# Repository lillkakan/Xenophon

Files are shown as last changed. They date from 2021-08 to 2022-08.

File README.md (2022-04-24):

# Xenophon split keyboard

Xenophon is a split keyboard with a design based on the ErgoDox EZ but for less keys for the thumps and another layout for the side keys.

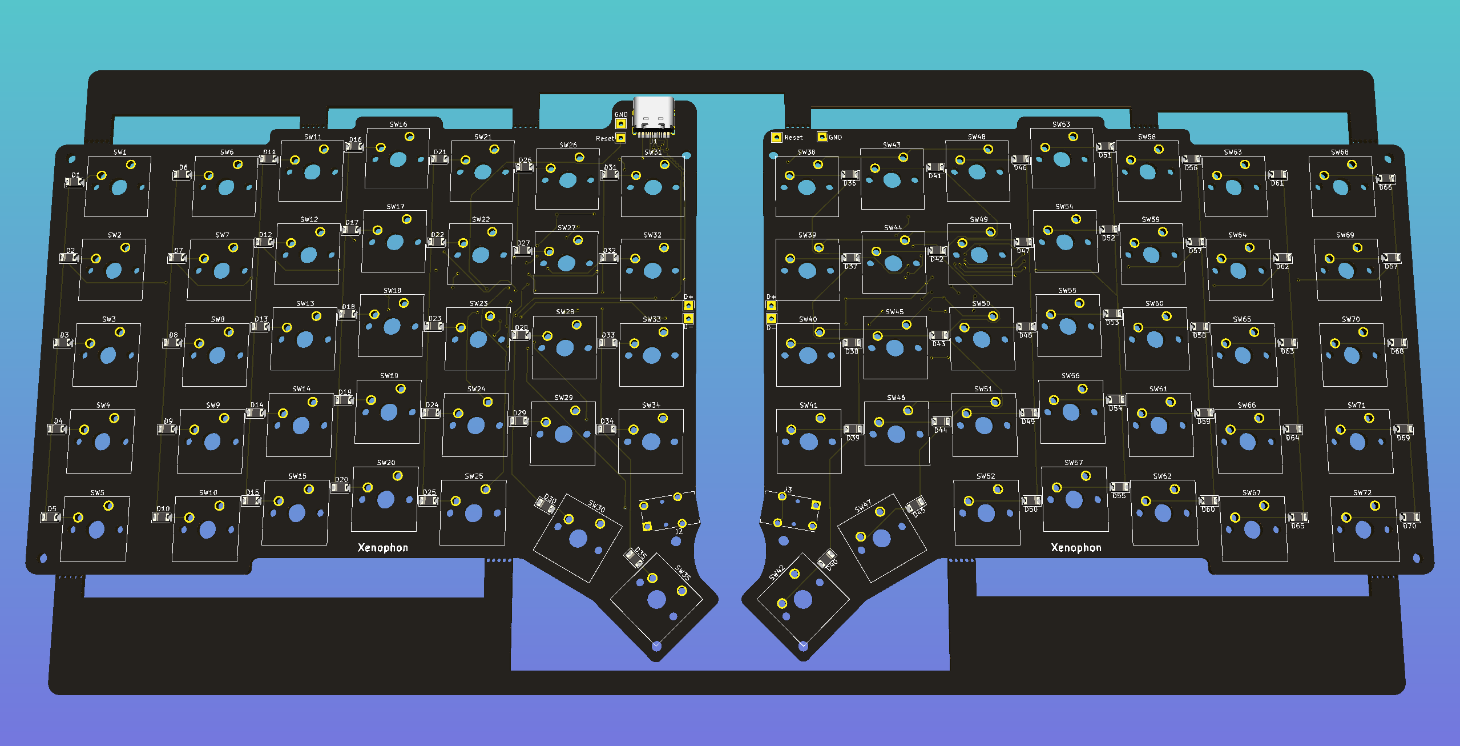
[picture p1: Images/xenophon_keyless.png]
The PCB for the keyboard.


## Features

### Ortholinear design

The keyboard features an ortholinear design based on the ErgoDox EZ.

### 70 buttons

The keyboard features 70 buttons to replicate a standard 60% keyboard as much as possible.
The Default layout is in swedish and has all the letters and numbers.

### TRS jack connection

The PCB is designed with a trs jack nicley placed between the tilted keys.
The two processors sent data through the serial bitbang protocol.

### Smart flashing design

I did not want to include a usb port on the right PCB i added two usb pins (D+ and D-) on both sides so that i could solder all the componens except the left processors and flash the right side easily.

### USB-C

The PCB features a usb type c port with capability to connect via a usb-c to usb-c cable or a standard usb-c to usb-a cable.

### 3D printable chassi

The chassi for the keyboard is 3D printable and is designed to be as small as possible while still protecting the PCB and the electrical components.

### Relativly low cost

The total cost of the key board is around 1 300 SEK.
Which is less than similar keyboards like the ErgoDox EZ.

## Made with

Quantum Mechanical Keyboard Firmware: [qmk_firmware](https://github.com/qmk/qmk_firmware)

### Made with help from

Keyboard layout editor: [keyboard-layout-editor.com](http://www.keyboard-layout-editor.com/)

Parametric Mechanical Keycap Library: [KeyV2](https://github.com/rsheldiii/KeyV2)

Keyboard Firmware Builder: [kbfirmware.com](https://kbfirmware.com/)

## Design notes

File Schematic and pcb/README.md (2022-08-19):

# Xenophon Schematic and PCB

### Schematic

Feutures a usb-c connection on the left (master) side.

Because I wanted the right PCB to have as few IO connectors as possible i made the decision to place two pin holes connected to the USB pins on the processor.
This made is so I could connect the USB pins on the left side with the ones on the right side and flash the right processor with the USB-C cable before i soldered the left processor.
The two pins can also be connected to two resistors and soldered to a USB cable to flash to the processor directly.

Small reset buttons take up unneccesary space on the pcb i added pins for for both sides reset connection designed so that a regular cable could pull the reset down.

### Components

- 70x Cherry switches
- 70x Diodes
- 1x  USB-C Receptacle
- 2x  Atmega 32u4
- 2x  16 Mhz Crystal
- 2x  3.5 TRS jack
- 5x  0.1u  Capacitor
- 4x  18p   Capacitor
- 2x  1u    Capacitor
- 1x  4.7u  Capacitor
- 4x  10k   Ohm Resistors
- 2x  22    Ohm Resistors
- 2x  5.1k  Ohm Resistors

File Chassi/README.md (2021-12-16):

# Xenophon

The base is made using FreeCAD and can be 3D printed and applied to the PCB directly.

The PCB features small stud holes which fits on the studs on the chassi.
Because these holes are small there is a stud tester i printed to confirm that my 3D printers settings would work.

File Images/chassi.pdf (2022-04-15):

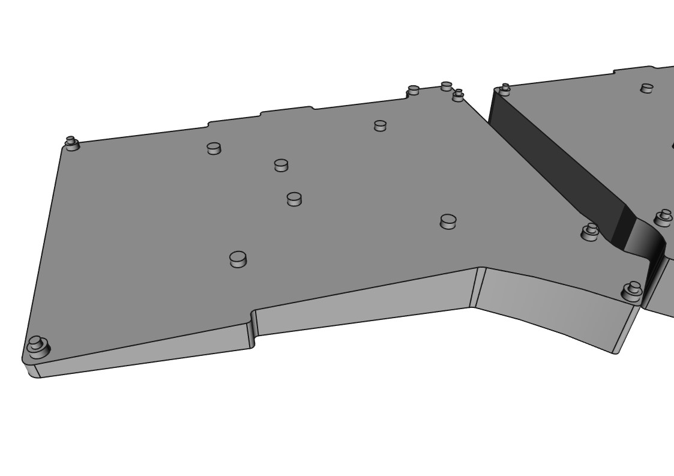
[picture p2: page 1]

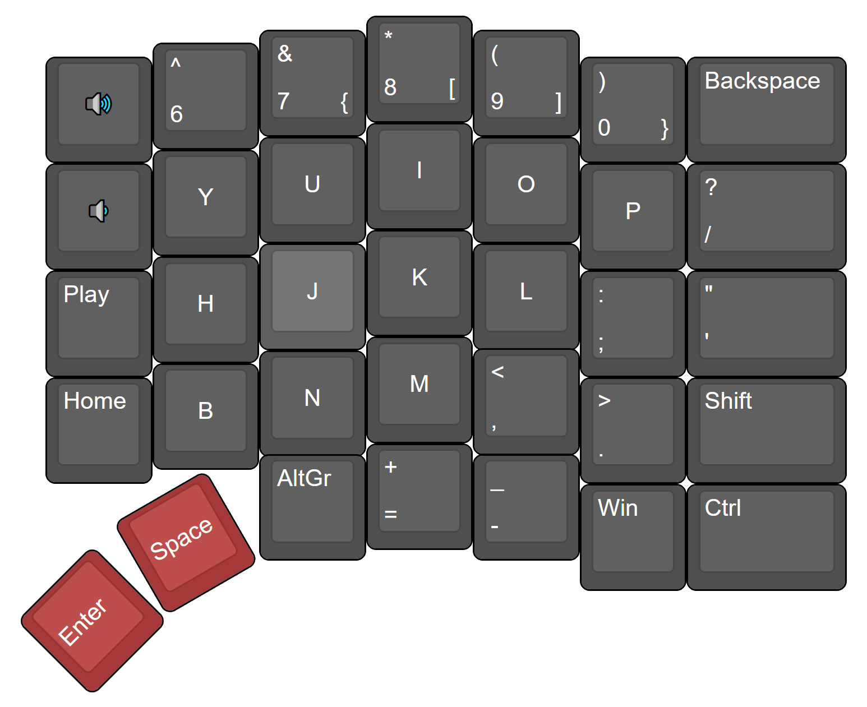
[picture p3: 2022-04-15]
Images/layouts/intRight.png

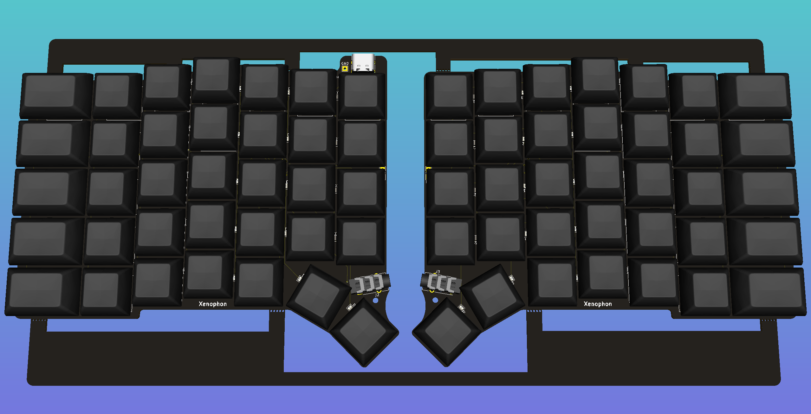
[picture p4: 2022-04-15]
Images/xenophon.png

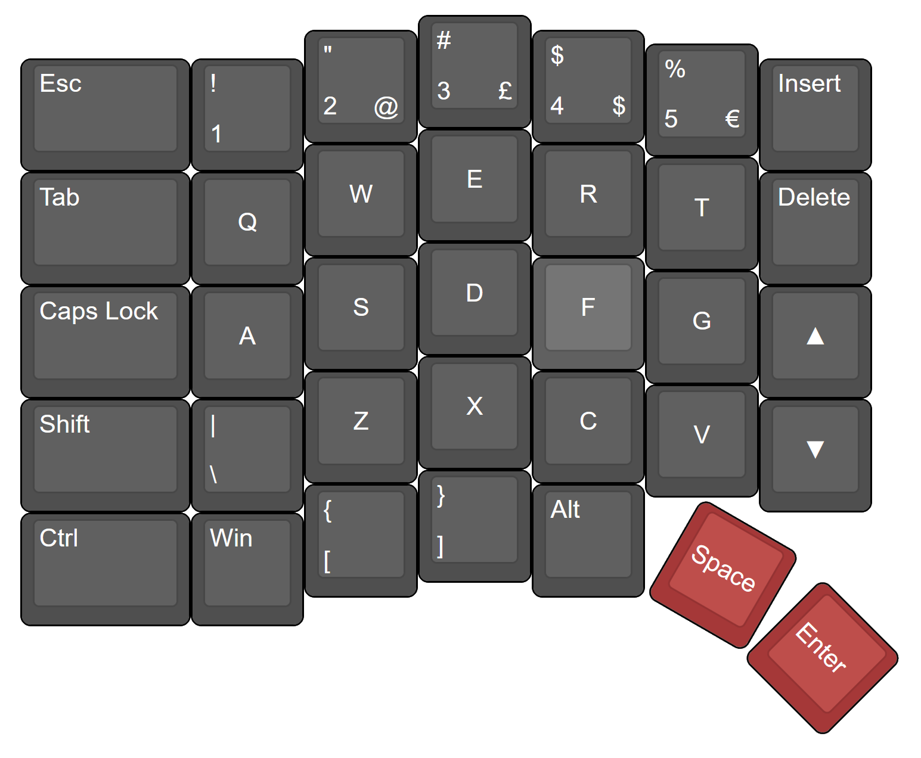
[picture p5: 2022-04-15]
Images/layouts/intLeft.png

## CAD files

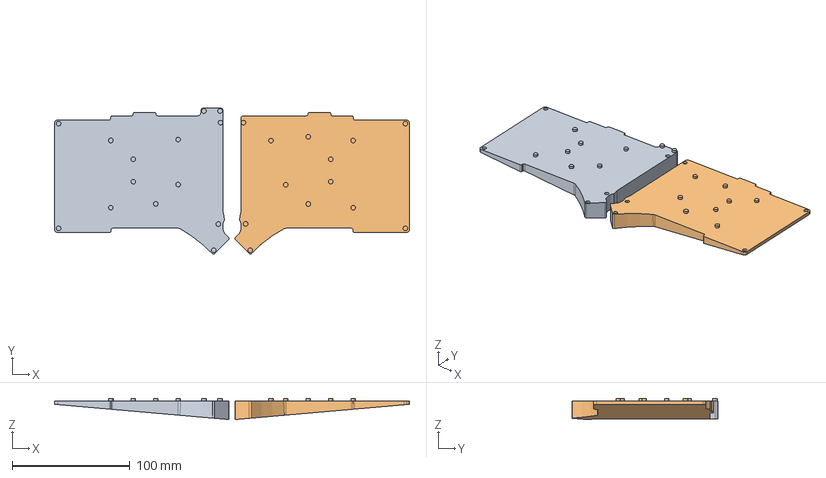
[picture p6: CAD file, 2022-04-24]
Chassi/base_tilted.FCStd
301.4 x 124.2 x 18.0 mm
Left
Right

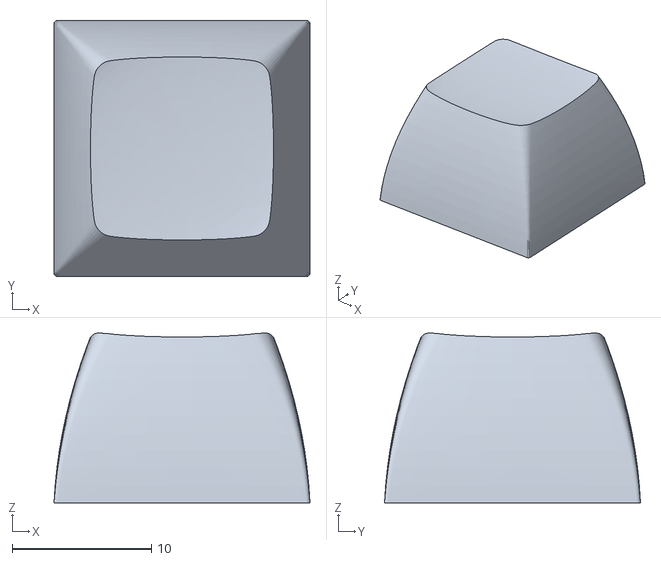
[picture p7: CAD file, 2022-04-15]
Chassi/Keys/sa.stl
18.4 x 18.4 x 12.2

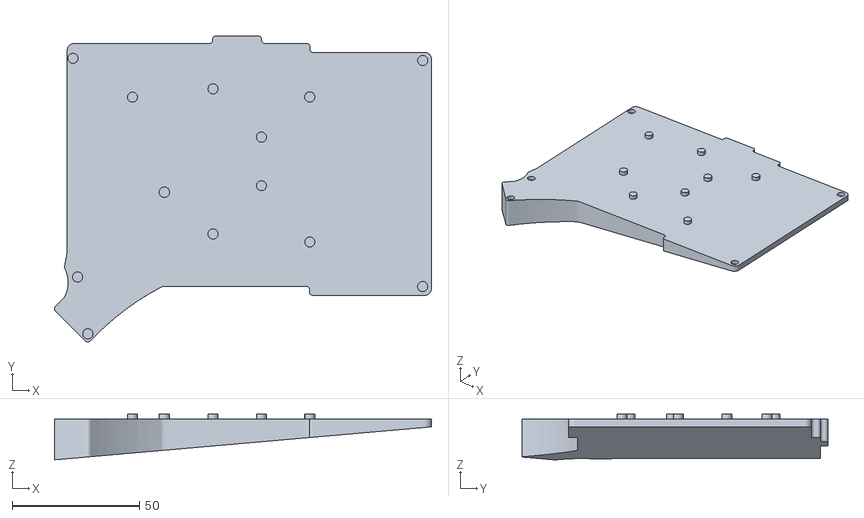
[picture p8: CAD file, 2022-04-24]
Chassi/STL files/base_tilted-Right.stl
148.2 x 120.3 x 18.0

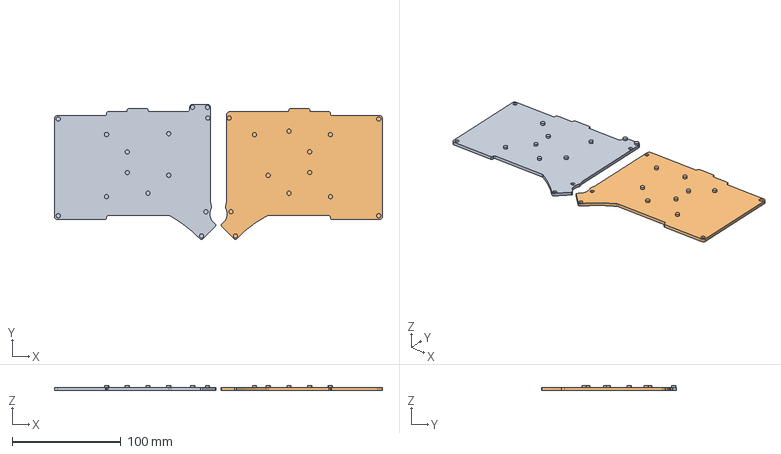
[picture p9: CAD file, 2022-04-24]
Chassi/base.FCStd
301.4 x 124.2 x 5.00 mm
Left
Right

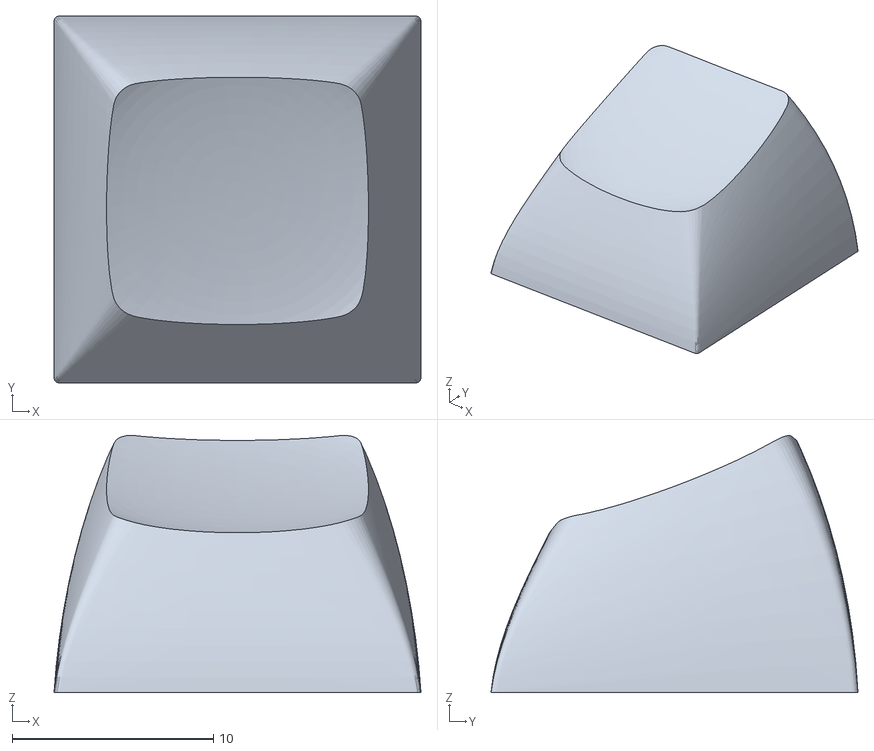
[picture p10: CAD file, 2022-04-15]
Chassi/Keys/dsa_r5.stl
18.2 x 18.2 x 12.8

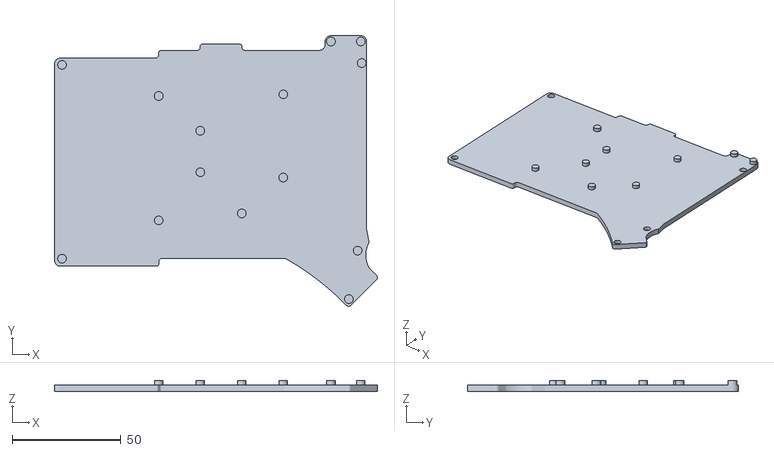
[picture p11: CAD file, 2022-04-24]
Chassi/STL files/base-Left.stl
148.2 x 124.2 x 5.00

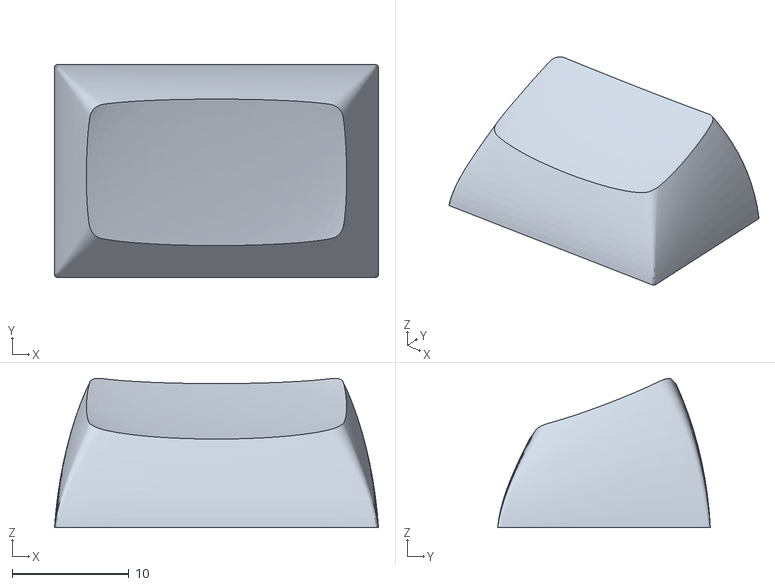
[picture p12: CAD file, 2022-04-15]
Chassi/Keys/dsa_r5_u1_5.stl
27.8 x 18.2 x 12.8

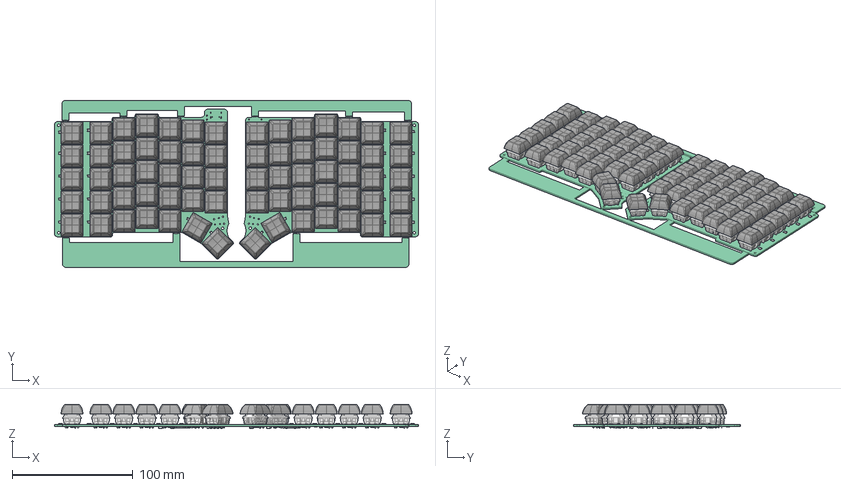
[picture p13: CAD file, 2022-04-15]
Chassi/PCB.FCStd
301.4 x 138.2 x 19.9 mm
Pcb_2136
SW1_SW_Cherry_MX_PCB_cp_61322BA2[2] x 70
SW1_Keycap_adjusted v39_61322BA2[3] x 70
D68_D_1206_61321C2C x 70
C12_C_1206_3216Metric_613218D6 x 12
U2_TQFP_44_10x10mm_P08mm_6.1321e+103 x 2
R8_R_1206_3216Metric_6.1322e+19 x 8

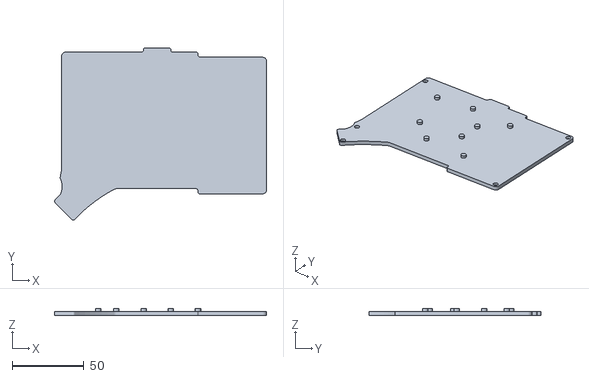
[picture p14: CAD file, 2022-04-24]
Chassi/STL files/base-Right.stl
148.2 x 120.3 x 5.00

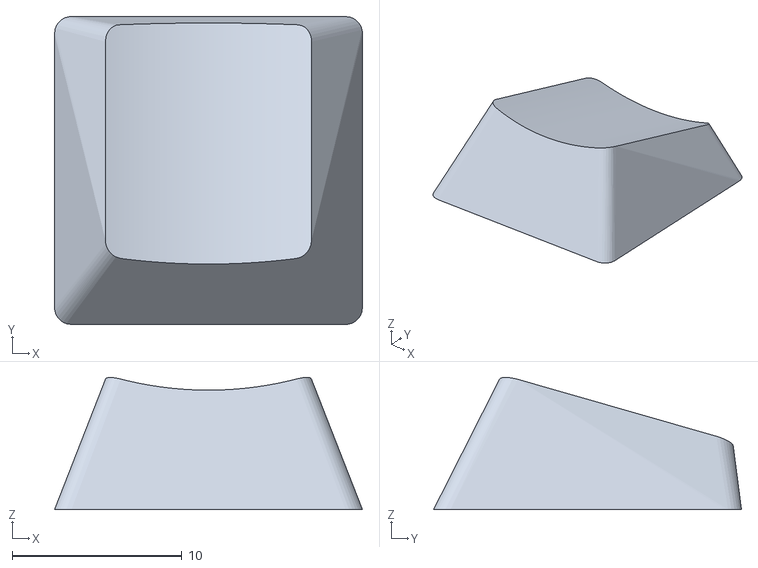
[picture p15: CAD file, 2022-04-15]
Chassi/Keys/dcs_r4.stl
18.2 x 18.2 x 7.79

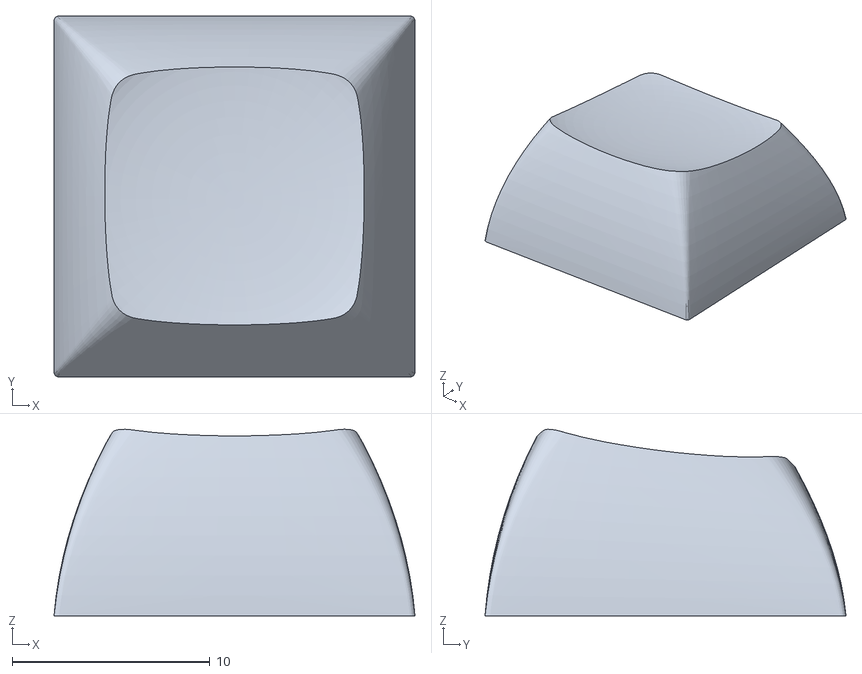
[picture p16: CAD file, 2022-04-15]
Chassi/Keys/dsa_r4.stl
18.2 x 18.2 x 9.43

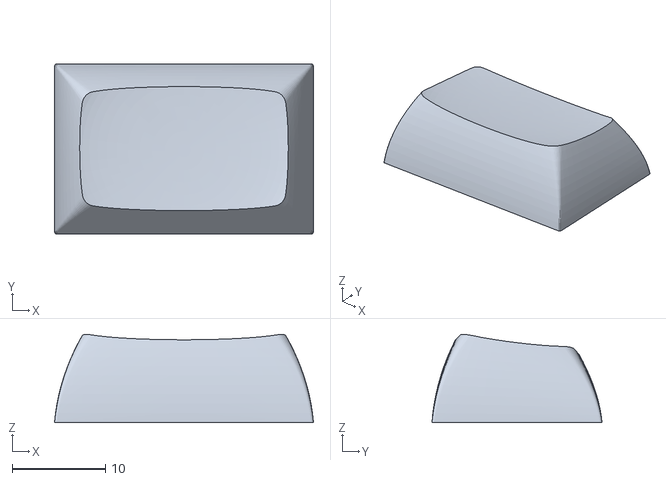
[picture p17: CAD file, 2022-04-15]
Chassi/Keys/dsa_r4_u1_5.stl
27.8 x 18.2 x 9.46

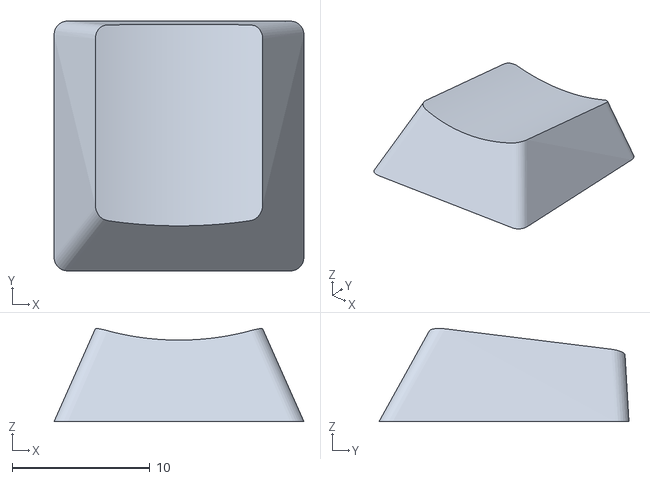
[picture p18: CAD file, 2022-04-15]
Chassi/Keys/dcs_r3.stl
18.2 x 18.2 x 6.77

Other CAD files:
Chassi/STL files/base_tilted-Left.stl

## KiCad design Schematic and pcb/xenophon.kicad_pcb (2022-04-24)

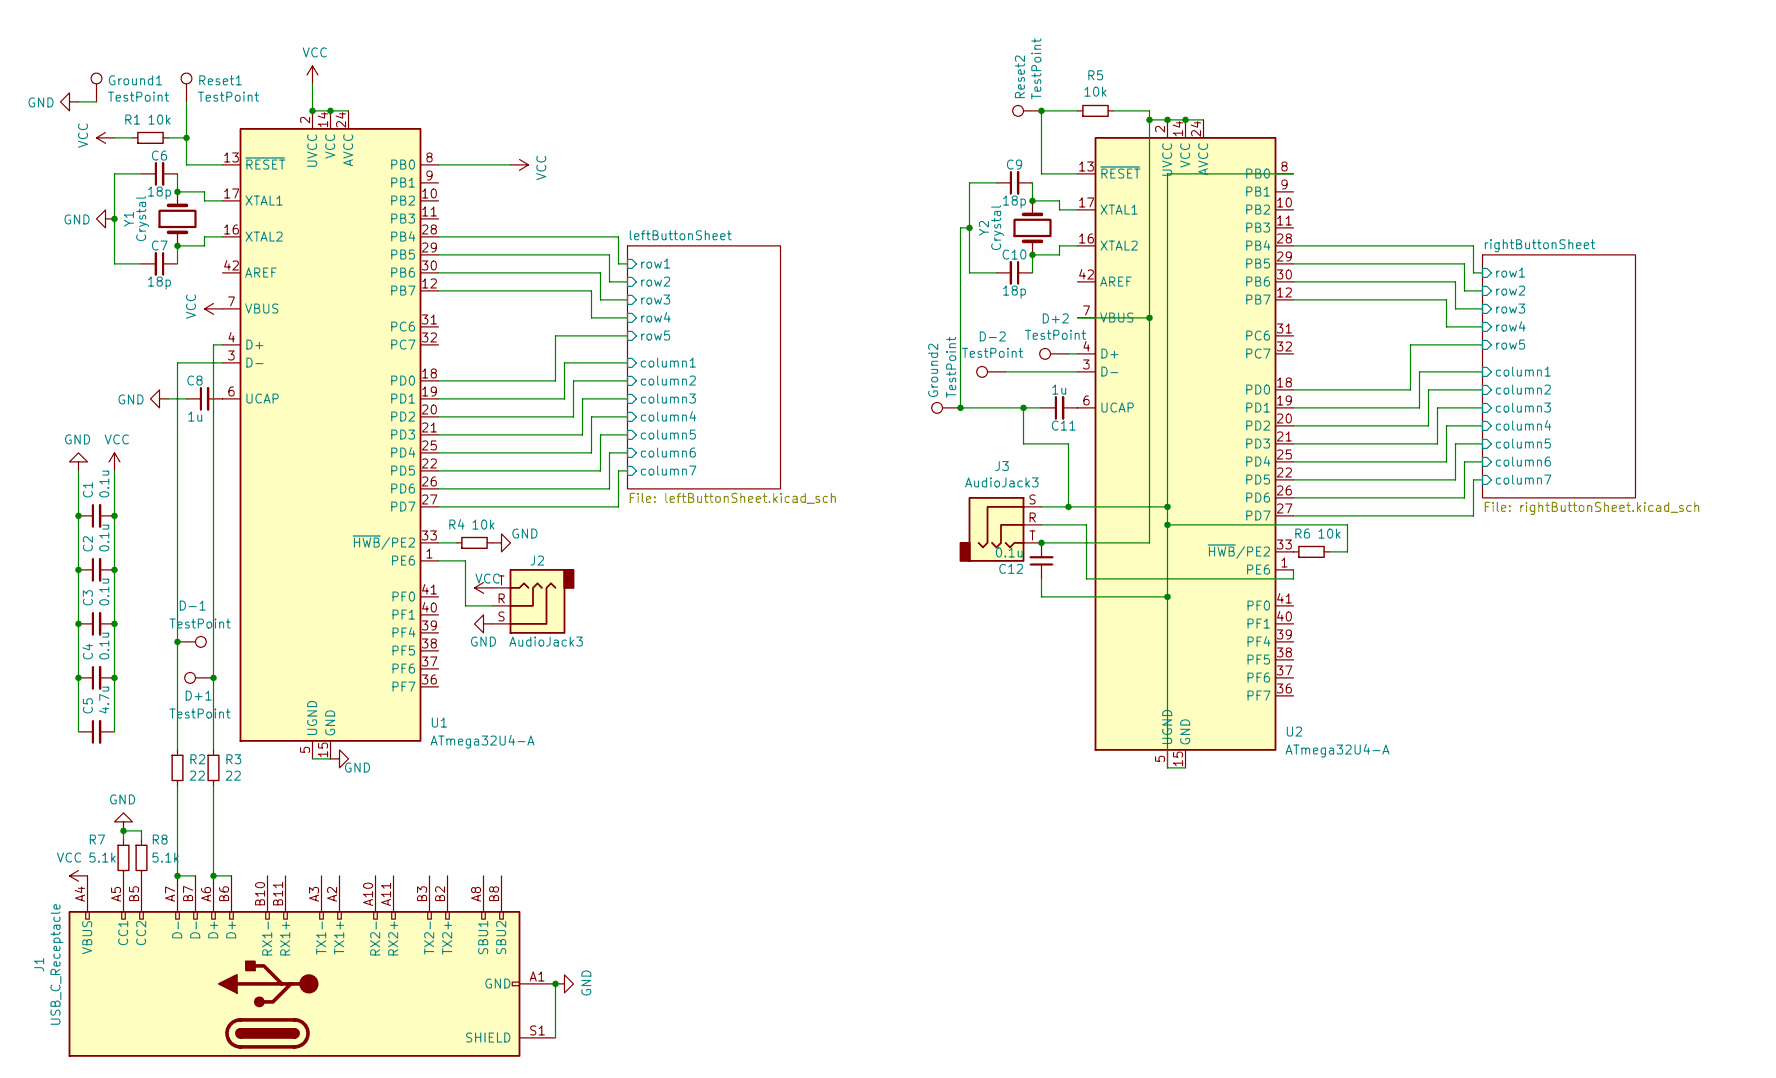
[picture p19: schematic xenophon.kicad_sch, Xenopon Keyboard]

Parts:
C1, C2, C3, C4, C12: 0.1u; C_1206_3216Metric
C5: 4.7u; C_1206_3216Metric
C6, C7, C9, C10: 18p; C_1206_3216Metric
C8, C11: 1u; C_1206_3216Metric
D+1, D+2: TestPoint; TestPoint_THTPad_2.0x2.0mm_Drill1.0mm
D-1, D-2: TestPoint; TestPoint_THTPad_2.0x2.0mm_Drill1.0mm
Ground1, Ground2: TestPoint; TestPoint_THTPad_2.0x2.0mm_Drill1.0mm
J1: USB_C_Receptacle; USB_C_Receptacle_HRO_TYPE-C-31-M-12
J2, J3: AudioJack3; Jack_3.5mm_Switronic_ST-005-G_horizontal
R1, R4, R5, R6: 10k; R_1206_3216Metric
R2, R3: 22; R_1206_3216Metric
R7, R8: 5.1k; R_1206_3216Metric
Reset1, Reset2: TestPoint; TestPoint_THTPad_2.0x2.0mm_Drill1.0mm
U1, U2: ATmega32U4-A; TQFP-44_10x10mm_P0.8mm
Y1, Y2: Crystal; Crystal_SMD_2016-4Pin_2.0x1.6mm

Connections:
/leftButtonSheet/column1: U1.19 (PD1); also elsewhere on the board
/leftButtonSheet/column2: U1.20 (PD2); also elsewhere on the board
/leftButtonSheet/column3: U1.21 (PD3); also elsewhere on the board
/leftButtonSheet/column4: U1.25 (PD4); also elsewhere on the board
/leftButtonSheet/column5: U1.22 (PD5); also elsewhere on the board
/leftButtonSheet/column6: U1.26 (PD6); also elsewhere on the board
/leftButtonSheet/column7: U1.27 (PD7); also elsewhere on the board
/leftButtonSheet/row1: U1.28 (PB4); also elsewhere on the board
/leftButtonSheet/row2: U1.29 (PB5); also elsewhere on the board
/leftButtonSheet/row3: U1.30 (PB6); also elsewhere on the board
/leftButtonSheet/row4: U1.12 (PB7); also elsewhere on the board
/leftButtonSheet/row5: U1.18 (PD0); also elsewhere on the board
/rightButtonSheet/column1: U2.19 (PD1); also elsewhere on the board
/rightButtonSheet/column2: U2.20 (PD2); also elsewhere on the board
/rightButtonSheet/column3: U2.21 (PD3); also elsewhere on the board
/rightButtonSheet/column4: U2.25 (PD4); also elsewhere on the board
/rightButtonSheet/column5: U2.22 (PD5); also elsewhere on the board
/rightButtonSheet/column6: U2.26 (PD6); also elsewhere on the board
/rightButtonSheet/column7: U2.27 (PD7); also elsewhere on the board
/rightButtonSheet/row1: U2.28 (PB4); also elsewhere on the board
/rightButtonSheet/row2: U2.29 (PB5); also elsewhere on the board
/rightButtonSheet/row3: U2.30 (PB6); also elsewhere on the board
/rightButtonSheet/row4: U2.12 (PB7); also elsewhere on the board
/rightButtonSheet/row5: U2.18 (PD0); also elsewhere on the board
unnamed: C7.1, U1.16 (XTAL2), Y1.1
unnamed: C8.2, U1.6 (UCAP)
unnamed: C10.1, U2.16 (XTAL2), Y2.1
unnamed: C11.2, U2.6 (UCAP)
unnamed: C12.2, J3.T, R5.2, U2.2 (UVCC), U2.7 (VBUS), U2.14 (VCC), U2.24 (AVCC), U2.34 (VCC), U2.44 (AVCC)
unnamed 99: D+1.1, R3.1, U1.4 (D+); also elsewhere on the board
unnamed 100: D+2.1, U2.4 (D+); also elsewhere on the board
unnamed 101: D-1.1, R2.1, U1.3 (D-); also elsewhere on the board
unnamed 102: D-2.1, U2.3 (D-); also elsewhere on the board
unnamed: J1.A5 (CC1), R7.2
unnamed: J1.A6 (D+), J1.B6 (D+), R3.2
unnamed: J1.A7 (D-), J1.B7 (D-), R2.2
unnamed: J1.B5 (CC2), R8.2
unnamed: J2.R, U1.1 (PE6)
unnamed: J3.R, U2.1 (PE6)
unnamed 111: R1.2, Reset1.1, U1.13 (~RESET); also elsewhere on the board
unnamed: R4.1, U1.33 (~HWB/PE2)
unnamed 113: R5.1, Reset2.1, U2.13 (~RESET); also elsewhere on the board
unnamed: R6.1, U2.33 (~HWB/PE2)
VCC: C1.2, C2.2, C3.2, C4.2, C5.2, J1.A4 (VBUS), J1.A9 (VBUS), J1.B4 (VBUS), J1.B9 (VBUS), J2.T, R1.1, U1.2 (UVCC), U1.7 (VBUS), U1.8 (PB0), U1.14 (VCC), U1.24 (AVCC), U1.34 (VCC), U1.44 (AVCC)

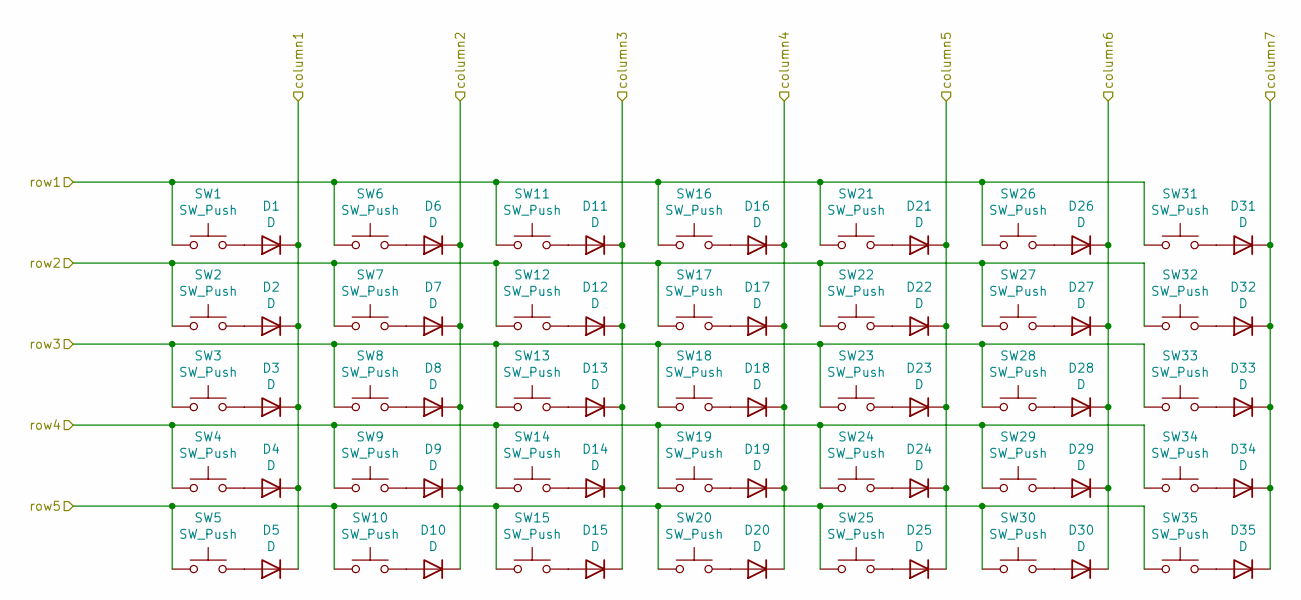
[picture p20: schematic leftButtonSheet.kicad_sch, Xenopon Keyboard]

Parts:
D1, D2, D3, D4, D5, D6, D7, D8, D9, D10, D11, D12, D13, D14, D15, D16, D17, D18, D19, D20, D21, D22, D23, D24, D25, D26, D27, D28, D29, D30, D31, D32, D33, D34, D35: D; D_1206_3216Metric
SW1, SW2, SW3, SW4, SW5: SW_Push; SW_Cherry_MX_1.50u_PCB
SW6, SW7, SW8, SW9, SW10, SW11, SW12, SW13, SW14, SW15, SW16, SW17, SW18, SW19, SW20, SW21, SW22, SW23, SW24, SW25, SW26, SW27, SW28, SW29, SW30, SW31, SW32, SW33, SW34, SW35: SW_Push; SW_Cherry_MX_1.00u_PCB

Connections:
/leftButtonSheet/column1: D1.1 (K), D2.1 (K), D3.1 (K), D4.1 (K), D5.1 (K); also elsewhere on the board
/leftButtonSheet/column2: D6.1 (K), D7.1 (K), D8.1 (K), D9.1 (K), D10.1 (K); also elsewhere on the board
/leftButtonSheet/column3: D11.1 (K), D12.1 (K), D13.1 (K), D14.1 (K), D15.1 (K); also elsewhere on the board
/leftButtonSheet/column4: D16.1 (K), D17.1 (K), D18.1 (K), D19.1 (K), D20.1 (K); also elsewhere on the board
/leftButtonSheet/column5: D21.1 (K), D22.1 (K), D23.1 (K), D24.1 (K), D25.1 (K); also elsewhere on the board
/leftButtonSheet/column6: D26.1 (K), D27.1 (K), D28.1 (K), D29.1 (K), D30.1 (K); also elsewhere on the board
/leftButtonSheet/column7: D31.1 (K), D32.1 (K), D33.1 (K), D34.1 (K), D35.1 (K); also elsewhere on the board
/leftButtonSheet/row1: SW1.1, SW6.1, SW11.1, SW16.1, SW21.1, SW26.1, SW31.1; also elsewhere on the board
/leftButtonSheet/row2: SW2.1, SW7.1, SW12.1, SW17.1, SW22.1, SW27.1, SW32.1; also elsewhere on the board
/leftButtonSheet/row3: SW3.1, SW8.1, SW13.1, SW18.1, SW23.1, SW28.1, SW33.1; also elsewhere on the board
/leftButtonSheet/row4: SW4.1, SW9.1, SW14.1, SW19.1, SW24.1, SW29.1, SW34.1; also elsewhere on the board
/leftButtonSheet/row5: SW5.1, SW10.1, SW15.1, SW20.1, SW25.1, SW30.1, SW35.1; also elsewhere on the board
unnamed: D1.2 (A), SW1.2
unnamed: D2.2 (A), SW2.2
unnamed: D3.2 (A), SW3.2
unnamed: D4.2 (A), SW4.2
unnamed: D5.2 (A), SW5.2
unnamed: D6.2 (A), SW6.2
unnamed: D7.2 (A), SW7.2
unnamed: D8.2 (A), SW8.2
unnamed: D9.2 (A), SW9.2
unnamed: D10.2 (A), SW10.2
unnamed: D11.2 (A), SW11.2
unnamed: D12.2 (A), SW12.2
unnamed: D13.2 (A), SW13.2
unnamed: D14.2 (A), SW14.2
unnamed: D15.2 (A), SW15.2
unnamed: D16.2 (A), SW16.2
unnamed: D17.2 (A), SW17.2
unnamed: D18.2 (A), SW18.2
unnamed: D19.2 (A), SW19.2
unnamed: D20.2 (A), SW20.2
unnamed: D21.2 (A), SW21.2
unnamed: D22.2 (A), SW22.2
unnamed: D23.2 (A), SW23.2
unnamed: D24.2 (A), SW24.2
unnamed: D25.2 (A), SW25.2
unnamed: D26.2 (A), SW26.2
unnamed: D27.2 (A), SW27.2
unnamed: D28.2 (A), SW28.2
unnamed: D29.2 (A), SW29.2
unnamed: D30.2 (A), SW30.2
unnamed: D31.2 (A), SW31.2
unnamed: D32.2 (A), SW32.2
unnamed: D33.2 (A), SW33.2
unnamed: D34.2 (A), SW34.2
unnamed: D35.2 (A), SW35.2

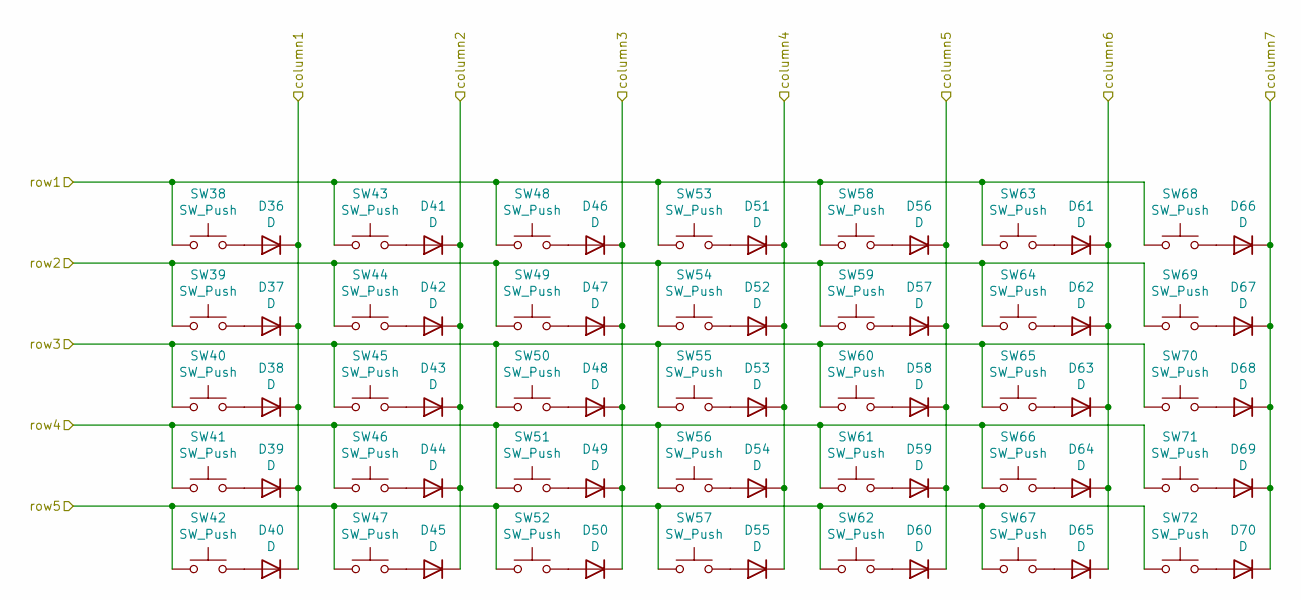
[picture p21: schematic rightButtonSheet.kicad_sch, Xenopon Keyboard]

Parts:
D36, D37, D38, D39, D40, D41, D42, D43, D44, D45, D46, D47, D48, D49, D50, D51, D52, D53, D54, D55, D56, D57, D58, D59, D60, D61, D62, D63, D64, D65, D66, D67, D68, D69, D70: D; D_1206_3216Metric
SW38, SW39, SW40, SW41, SW42, SW43, SW44, SW45, SW46, SW47, SW48, SW49, SW50, SW51, SW52, SW53, SW54, SW55, SW56, SW57, SW58, SW59, SW60, SW61, SW62, SW63, SW64, SW65, SW66, SW67: SW_Push; SW_Cherry_MX_1.00u_PCB
SW68, SW69, SW70, SW71, SW72: SW_Push; SW_Cherry_MX_1.50u_PCB

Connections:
/rightButtonSheet/column1: D36.1 (K), D37.1 (K), D38.1 (K), D39.1 (K), D40.1 (K); also elsewhere on the board
/rightButtonSheet/column2: D41.1 (K), D42.1 (K), D43.1 (K), D44.1 (K), D45.1 (K); also elsewhere on the board
/rightButtonSheet/column3: D46.1 (K), D47.1 (K), D48.1 (K), D49.1 (K), D50.1 (K); also elsewhere on the board
/rightButtonSheet/column4: D51.1 (K), D52.1 (K), D53.1 (K), D54.1 (K), D55.1 (K); also elsewhere on the board
/rightButtonSheet/column5: D56.1 (K), D57.1 (K), D58.1 (K), D59.1 (K), D60.1 (K); also elsewhere on the board
/rightButtonSheet/column6: D61.1 (K), D62.1 (K), D63.1 (K), D64.1 (K), D65.1 (K); also elsewhere on the board
/rightButtonSheet/column7: D66.1 (K), D67.1 (K), D68.1 (K), D69.1 (K), D70.1 (K); also elsewhere on the board
/rightButtonSheet/row1: SW38.1, SW43.1, SW48.1, SW53.1, SW58.1, SW63.1, SW68.1; also elsewhere on the board
/rightButtonSheet/row2: SW39.1, SW44.1, SW49.1, SW54.1, SW59.1, SW64.1, SW69.1; also elsewhere on the board
/rightButtonSheet/row3: SW40.1, SW45.1, SW50.1, SW55.1, SW60.1, SW65.1, SW70.1; also elsewhere on the board
/rightButtonSheet/row4: SW41.1, SW46.1, SW51.1, SW56.1, SW61.1, SW66.1, SW71.1; also elsewhere on the board
/rightButtonSheet/row5: SW42.1, SW47.1, SW52.1, SW57.1, SW62.1, SW67.1, SW72.1; also elsewhere on the board
unnamed: D36.2 (A), SW38.2
unnamed: D37.2 (A), SW39.2
unnamed: D38.2 (A), SW40.2
unnamed: D39.2 (A), SW41.2
unnamed: D40.2 (A), SW42.2
unnamed: D41.2 (A), SW43.2
unnamed: D42.2 (A), SW44.2
unnamed: D43.2 (A), SW45.2
unnamed: D44.2 (A), SW46.2
unnamed: D45.2 (A), SW47.2
unnamed: D46.2 (A), SW48.2
unnamed: D47.2 (A), SW49.2
unnamed: D48.2 (A), SW50.2
unnamed: D49.2 (A), SW51.2
unnamed: D50.2 (A), SW52.2
unnamed: D51.2 (A), SW53.2
unnamed: D52.2 (A), SW54.2
unnamed: D53.2 (A), SW55.2
unnamed: D54.2 (A), SW56.2
unnamed: D55.2 (A), SW57.2
unnamed: D56.2 (A), SW58.2
unnamed: D57.2 (A), SW59.2
unnamed: D58.2 (A), SW60.2
unnamed: D59.2 (A), SW61.2
unnamed: D60.2 (A), SW62.2
unnamed: D61.2 (A), SW63.2
unnamed: D62.2 (A), SW64.2
unnamed: D63.2 (A), SW65.2
unnamed: D64.2 (A), SW66.2
unnamed: D65.2 (A), SW67.2
unnamed: D66.2 (A), SW68.2
unnamed: D67.2 (A), SW69.2
unnamed: D68.2 (A), SW70.2
unnamed: D69.2 (A), SW71.2
unnamed: D70.2 (A), SW72.2

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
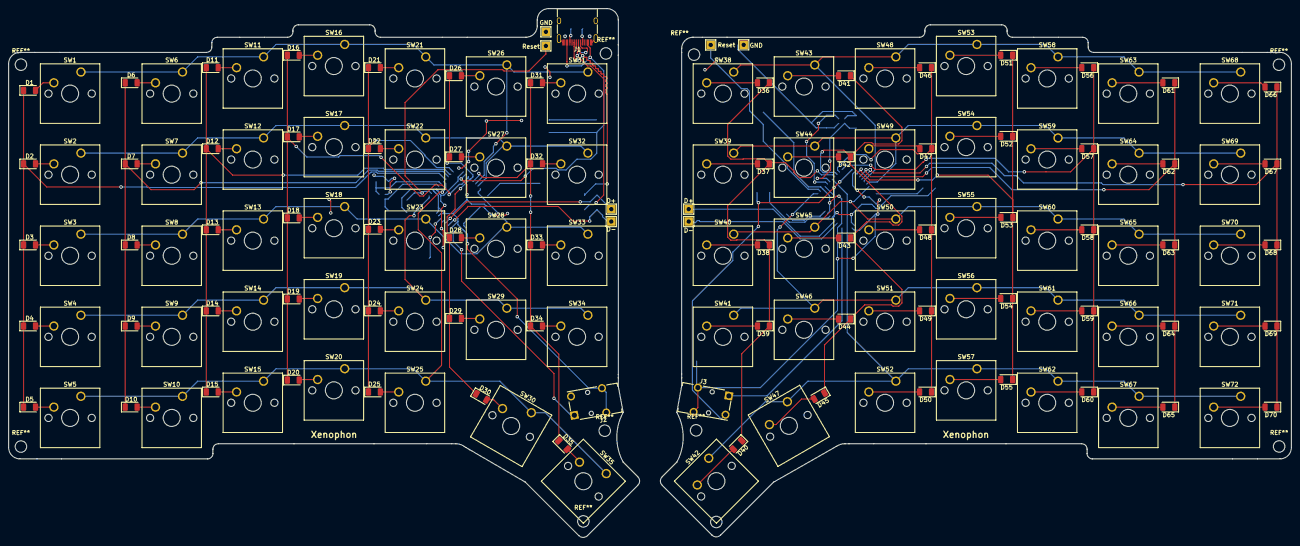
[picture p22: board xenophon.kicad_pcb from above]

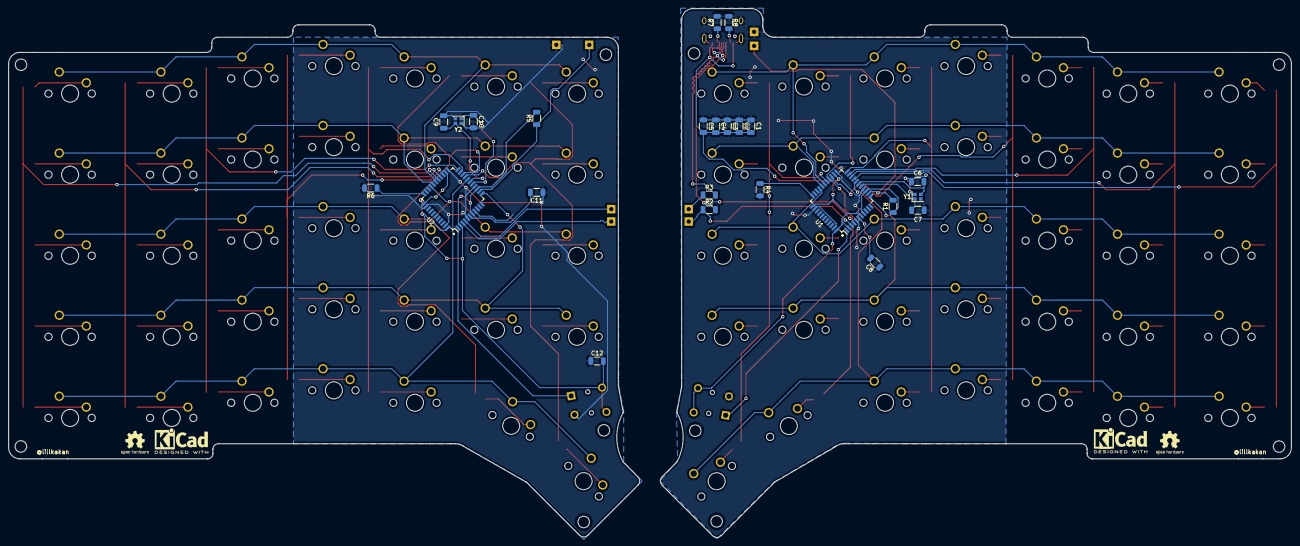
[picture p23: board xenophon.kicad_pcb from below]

Board: 2 copper layers, 301.4 x 124.2 mm, 175 parts (24 on the bottom side), 118 nets.

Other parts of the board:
D+: TestPoint; TestPoint_THTPad_2.0x2.0mm_Drill1.0mm
D+#2: TestPoint; TestPoint_THTPad_2.0x2.0mm_Drill1.0mm
D-: TestPoint; TestPoint_THTPad_2.0x2.0mm_Drill1.0mm
D-#2: TestPoint; TestPoint_THTPad_2.0x2.0mm_Drill1.0mm
GND: TestPoint; TestPoint_THTPad_2.0x2.0mm_Drill1.0mm
GND#2: TestPoint; TestPoint_THTPad_2.0x2.0mm_Drill1.0mm
Reset: TestPoint; TestPoint_THTPad_2.0x2.0mm_Drill1.0mm
Reset#2: TestPoint; TestPoint_THTPad_2.0x2.0mm_Drill1.0mm

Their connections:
unnamed 99: D+#2.1; also elsewhere on the board
unnamed 100: D+.1; also elsewhere on the board
unnamed 101: D-#2.1; also elsewhere on the board
unnamed 102: D-.1; also elsewhere on the board
unnamed 111: Reset.1; also elsewhere on the board
unnamed 113: Reset#2.1; also elsewhere on the board

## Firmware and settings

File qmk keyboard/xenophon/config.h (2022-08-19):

#ifndef CONFIG_H
#define CONFIG_H

#include "config_common.h"

/* USB Device descriptor parameter */
#define VENDOR_ID       0xC7AD
#define PRODUCT_ID      0x0E09
#define DEVICE_VER      0x0001
#define MANUFACTURER    @lillkakan
#define PRODUCT         xenophon

/* key matrix size */
#define MATRIX_ROWS 10
#define MATRIX_COLS 7

/* key matrix pins */
#define MATRIX_ROW_PINS { B4, B5, B6, B7, D0 }
#define MATRIX_COL_PINS { D1, D2, D3, D4, D5, D6, D7 }

/* Define spit attributes */
//#define SPLIT_HAND_PIN B0 // old

#define MASTER_LEFT

#define SOFT_SERIAL_PIN E6

#define SPLIT_USB_DETECT
#define SPLIT_USB_TIMEOUT 2000

/* COL2ROW or ROW2COL */
#define DIODE_DIRECTION ROW2COL

/* Set 0 if debouncing isn't needed */
// DEBOUNCING_DELAY in config.h is no longer a valid option and should be replaced with DEBOUNCE
#define DEBOUNCE 0

/* Makes tapping easyer */
#define TAPPING_TERM 150

/* Mechanical locking support. Use KC_LCAP, KC_LNUM or KC_LSCR instead in keymap */
#define LOCKING_SUPPORT_ENABLE

/* Locking resynchronize hack */
#define LOCKING_RESYNC_ENABLE

/* key combination for command 
#define IS_COMMAND() ( \
    keyboard_report->mods == (MOD_BIT(KC_LSHIFT) | MOD_BIT(KC_RSHIFT)) \
)
*/

/* prevent stuck modifiers */
// PREVENT_STUCK_MODIFIERS in config.h is no longer a valid option and should be removed
//#define PREVENT_STUCK_MODIFIERS

#endif

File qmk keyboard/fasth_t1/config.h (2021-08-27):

#ifndef CONFIG_H
#define CONFIG_H

#include "config_common.h"

/* USB Device descriptor parameter */
#define VENDOR_ID       0xFEED
#define PRODUCT_ID      0x6060
#define DEVICE_VER      0x0001
#define MANUFACTURER    qmkbuilder
#define PRODUCT         Fasth T1

/* key matrix size */
#define MATRIX_ROWS 10
#define MATRIX_COLS 7

/* key matrix pins */
#define MATRIX_ROW_PINS { B4, B5, B6, B7, D0 }
#define MATRIX_COL_PINS { D1, D2, D3, D4, D5, D6, D7 }
#define UNUSED_PINS

/* Define spit attributes */
#define SPLIT_HAND_PIN B0
#define SOFT_SERIAL_PIN E6

/* COL2ROW or ROW2COL */
#define DIODE_DIRECTION ROW2COL

/* number of backlight levels */

// #ifdef BACKLIGHT_PIN
// #define BACKLIGHT_LEVELS 3
// #endif

/* Set 0 if debouncing isn't needed */
#define DEBOUNCING_DELAY 5

/* Mechanical locking support. Use KC_LCAP, KC_LNUM or KC_LSCR instead in keymap */
#define LOCKING_SUPPORT_ENABLE

/* Locking resynchronize hack */
#define LOCKING_RESYNC_ENABLE

/* key combination for command */
#define IS_COMMAND() ( \
    keyboard_report->mods == (MOD_BIT(KC_LSHIFT) | MOD_BIT(KC_RSHIFT)) \
)

/* prevent stuck modifiers */
#define PREVENT_STUCK_MODIFIERS


#ifdef RGB_DI_PIN
#define RGBLIGHT_ANIMATIONS
#define RGBLED_NUM 0
#define RGBLIGHT_HUE_STEP 8
#define RGBLIGHT_SAT_STEP 8
#define RGBLIGHT_VAL_STEP 8
#endif

#endif

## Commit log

2021-08-27 tidy files
    [1_5u_row_0.stl, 1_5u_row_1.stl, 1_5u_row_2.stl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]
2021-09-02 New pcb design
    [T1-B_Cu.gbr, T1-B_Mask.gbr, T1-B_Paste.gbr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]
2021-09-07 Updated chassi base and removed key file
    [1_5u_row_0.stl, 1_5u_row_1.stl, 1_5u_row_2.stl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]
2021-09-07 Changed name
    [T1-B_Cu.gbr, T1-B_Mask.gbr, T1-B_Paste.gbr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]
2021-09-16 Wrote the intro readme.
    [Stud_test.stl, base-Left.stl, base-Right.stl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]
2021-12-15 Added images and title block for the schematic.
    [leftButtonSheet.sch, rightButtonSheet.sch, xenophon.kicad_pcb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]
2021-12-16 Removed shortcut and gerber file
2021-12-16 Removed unnecessary kicad files
2022-01-22 Updated the 3D models, made the chassi a bit smaller.
    [base-Left.stl, base-Left_tilted.stl, base-Right.stl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]
2022-01-22 Removed the backspace on the left side to make room for insert.
2022-04-15 Added 3d models to kicad footprints.
2022-04-15 Started working on new pcb design without pre defined outline
    [xenophon_No_outline.kicad_pcb]
2022-04-15 Added a library of printable keys.
    [dcs_r3.stl, dcs_r4.stl, dsa_r4.stl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]
2022-04-15 Updated chassi design
    [PCB.FCStd, Stud_test.stl, base-Left.stl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]
2022-04-15 Updated pcb and projekt files.
    [leftButtonSheet.sch, rightButtonSheet.sch, xenophon.kicad_pcb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]
2022-04-24 Small changes to the chassi and their filenames
    [base-Left.stl, base-Right.stl, base.FCStd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]
2022-04-24 Updated PCB files to the new verison of kicad.
    [leftButtonSheet.kicad_sch, leftButtonSheet.sch, rightButtonSheet.kicad_sch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]
